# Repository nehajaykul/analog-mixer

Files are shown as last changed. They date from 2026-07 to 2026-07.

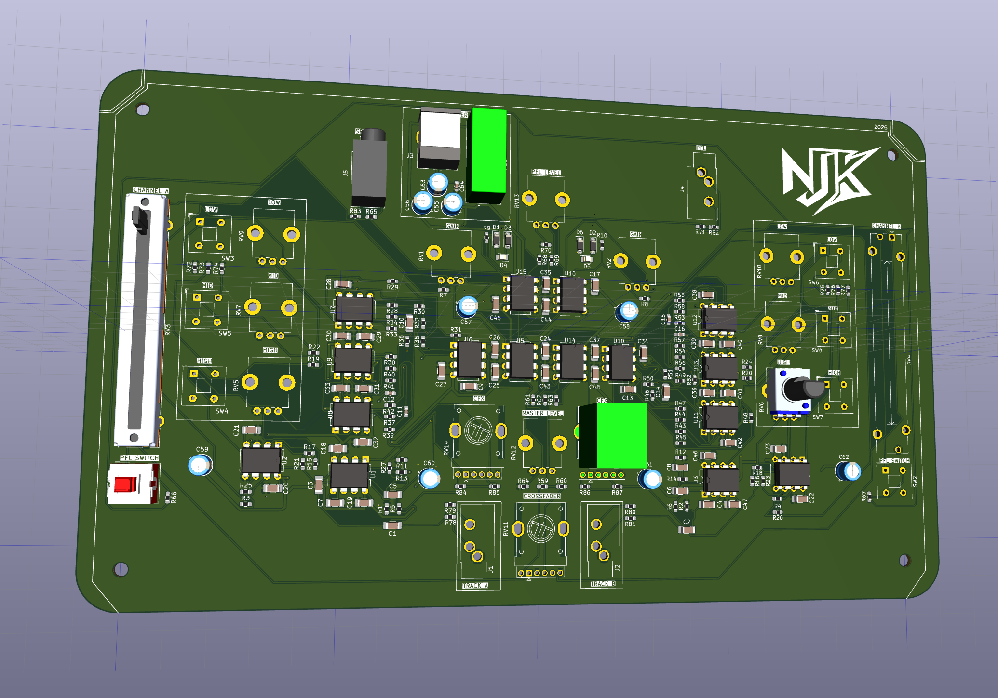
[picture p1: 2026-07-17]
docs/board_top.png

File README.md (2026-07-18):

# 2-Channel-Analog-DJ-Mixer

A fully analog 2-channel DJ mixer designed from first principles, 
simulated in LTspice, and laid out in KiCad for JLCPCB fabrication.

## Signal Chain

[3.5mm Input] → [L+R Sum] → [Sallen-Key HPF] → [SVF EQ Stage 1: 200Hz]
    → [SVF EQ Stage 2: 4kHz] → [Gain/Trim] → [Channel Fader]
    → [Crossfader] → [Virtual-Earth Sum] → [Master Output]

## Features

- 3-band parametric EQ per channel (HI/MID/LOW) with kill switches
- Cascaded Kerwin-Huelsman-Newcomb state-variable filters; Qs chosen for maximum passband flatness
  - Stage 1: f₀ = 200 Hz, Q = ~1.0
  - Stage 2: f₀ = 4 kHz, Q = ~.83
- Reduced summing-node phase cancellation, achieving <1.1 dB response variation across the band-pass (200 Hz–4 kHz)
- Pre-fader listen (PFL) cue system with headphone output; tapped after gain/trim stage and before channel fader
- Clipping LED indicator with 9.1V zener threshold (~11V signal threshold)
- Isolated ±15V dual-rail power supply (Traco TMR 6-1223)
- 15+ NE5532/TL072 op-amps throughout signal path

## Specifications

| Parameter | Value |
|---|---|
| Input | 3.5mm TRS, line level |
| EQ crossovers | 200 Hz, 4 kHz |
| EQ range | Cut to +14 dB per band |
| Power supply | 12V DC input → ±15V isolated |
| Op-amps | NE5532 (signal path), TL072 (monitor path) |
| PCB | 2-layer, JLCPCB fabrication |

## Repository Structure

```
/ltspice     — LTspice simulation files (.asc) for each circuit stage
/kicad       — KiCad schematic (.kicad_sch) and PCB layout (.kicad_pcb)
/gerbers     — Fabrication files for JLCPCB 2-layer PCB production
/docs        — Schematic PDF, simulation result plots, BOM
README.md    — Project overview
```

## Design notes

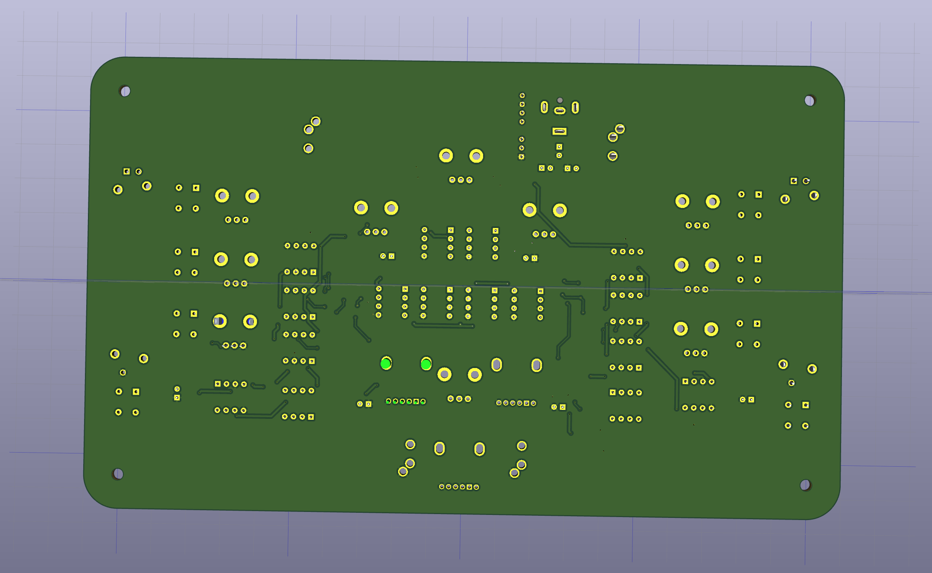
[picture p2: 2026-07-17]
docs/board_bottom.png

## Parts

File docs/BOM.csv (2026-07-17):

Id | Designator | Footprint | Quantity | Designation | Supplier and ref
1 | C19,C29,C28,C25,C14,C9,C45,C18,C42,C4,C41,C8,C32,C36,C47,C23,C1,C6,C44,C35,C46,C30,C26,C2,C43,C31,C22,C17,C33,C48,C20,C10,C40,C27,C37,C7,C34,C5,C38,C21,C3,C13,C39,C24 | C_1206_3216Metric_Pad1.33x1.80mm_HandSolder | 44 | 100n
2 | R29,R85,R59,R60,R24,R46,R21,R81,R58,R50,R69,R63,R87,R80,R54,R4,R20,R36,R19,R43,R44,R67,R30,R35,R22,R79,R84,R53,R27,R78,R66,R52,R42,R23,R37,R38,R86,R28,R61,R3,R25,R34,R51,R26,R45 | R_0603_1608Metric_Pad0.98x0.95mm_HandSolder | 45 | 10K
3 | SW4,SW6,SW7,SW5,SW3,SW2,SW1,SW8 | SW_Push_2P1T_Toggle_CK_PVA1xxH1xxxxxxV2 | 8 | SW_SPST
4 | RV11,RV15,RV14 | Potentiometer_Bourns_PTV112-4_Dual_Vertical | 3 | 10K
5 | R18,R62,R17,R15,R16 | R_0603_1608Metric_Pad0.98x0.95mm_HandSolder | 5 | 3.3K
6 | J5,J2,J1,J4 | Jack_3.5mm_CUI_SJ1-3533NG_Horizontal_CircularHoles | 4 | AudioJack3
7 | R65,R83 | R_0603_1608Metric_Pad0.98x0.95mm_HandSolder | 2 | 47
8 | RV7,RV12,RV9,RV2,RV13,RV10,RV8,RV1,RV6,RV5 | Potentiometer_Bourns_PTV09A-1_Single_Vertical | 10 | 50K
9 | U1,U8,U3,U6,U5,U11,U7,U4,U12,U10,U13,U2,U14,U9 | DIP-8_W7.62mm | 14 | NE5532
10 | R74,R75,R73,R77,R72,R76 | R_0603_1608Metric_Pad0.98x0.95mm_HandSolder | 6 | 100
11 | R11,R1,R12,R5,R2,R64,R14,R13,R6 | R_0603_1608Metric_Pad0.98x0.95mm_HandSolder | 9 | 100K
12 | R48,R32 | R_0603_1608Metric_Pad0.98x0.95mm_HandSolder | 2 | 5K
13 | R47,R49,R33,R31 | R_0603_1608Metric_Pad0.98x0.95mm_HandSolder | 4 | 8.2K
14 | D4,D5 | LED_0805_2012Metric_Pad1.15x1.40mm_HandSolder | 2 | D
15 | C55,C56,C58,C62,C60,C59,C63,C57,C61 | CP_Radial_D5.0mm_P2.50mm | 9 | 22u
16 | D6,D3,D2,D1 | D_SOD-123 | 4 | 9.1
17 | R9,R10 | R_0603_1608Metric_Pad0.98x0.95mm_HandSolder | 2 | 390
18 | R40,R56 | R_0603_1608Metric_Pad0.98x0.95mm_HandSolder | 2 | 6K
19 | C15,C11,C16,C12 | C_0603_1608Metric_Pad1.08x0.95mm_HandSolder | 4 | 10n
20 | R71,R82 | R_0603_1608Metric_Pad0.98x0.95mm_HandSolder | 2 | 150
21 | RV4,RV3 | Potentiometer_Bourns_PTA4543_Single_Slide | 2 | 10K
22 | R68 | R_0603_1608Metric_Pad0.98x0.95mm_HandSolder | 1 | 7.8K
23 | U16,U15 | DIP-8_W7.62mm | 2 | TL072
24 | R8,R70,R7 | R_0603_1608Metric_Pad0.98x0.95mm_HandSolder | 3 | 500
25 | R57,R55,R39,R41 | R_0603_1608Metric_Pad0.98x0.95mm_HandSolder | 4 | 3.9K
26 | C64 | C_0603_1608Metric_Pad1.08x0.95mm_HandSolder | 1 | 100n
27 | J3 | BarrelJack_CUI_PJ-063AH_Horizontal | 1 | Barrel_Jack
28 | PS1 | CONV_TMR_6-1223 | 1 | TMR_6-1223

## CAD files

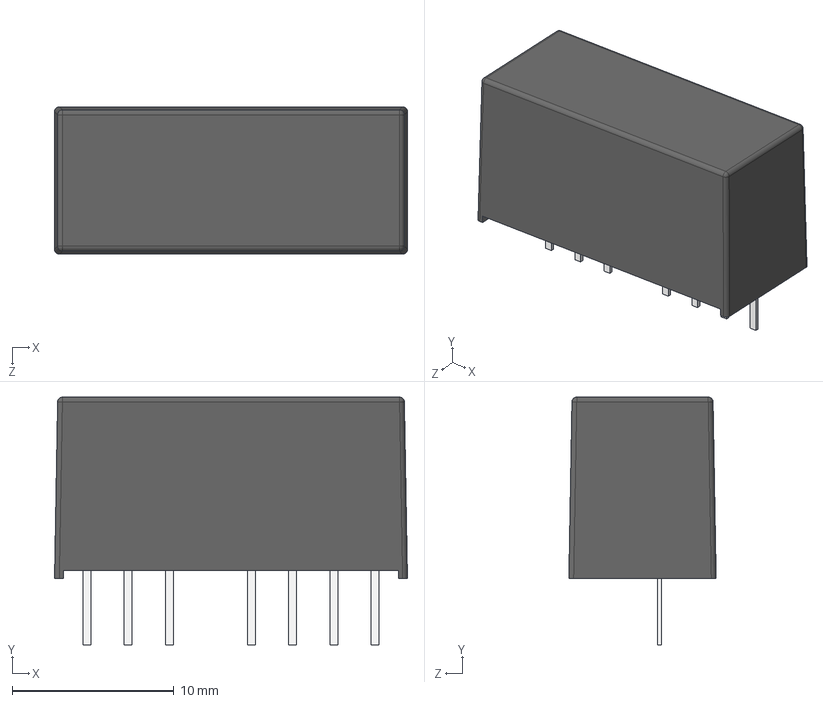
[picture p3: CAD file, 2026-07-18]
kicad/3dmodels/TMR_6-1223.step
21.8 x 15.3 x 9.10 mm

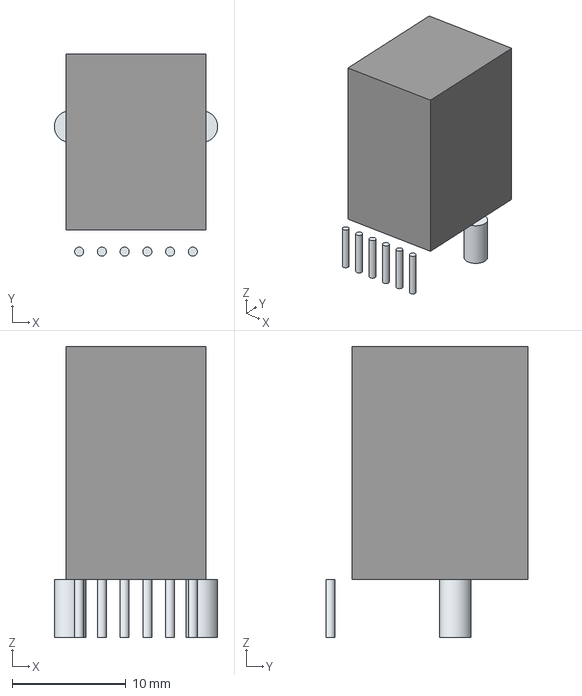
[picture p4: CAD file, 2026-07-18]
kicad/3dmodels/PTV112-4420A-B103.stp
14.4 x 17.8 x 25.6 mm
Leads x 8

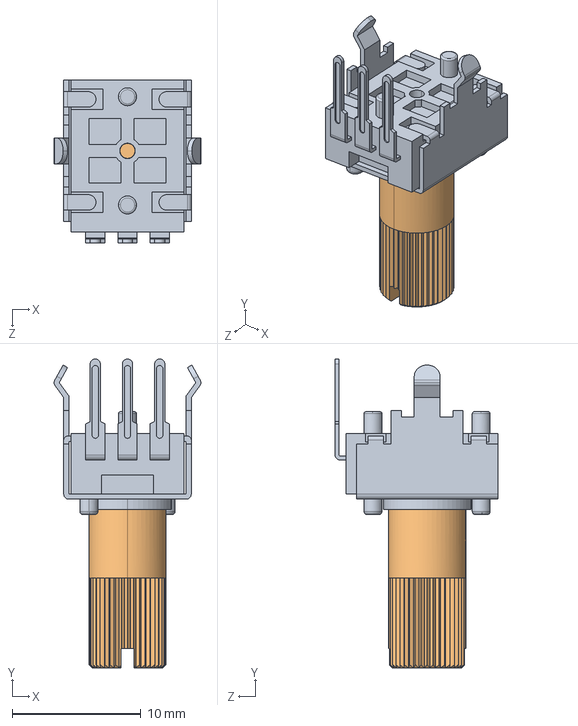
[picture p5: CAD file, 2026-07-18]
kicad/3dmodels/PTV09A-4020S-A503.stp
11.4 x 24.0 x 12.7 mm
PTV09A-4X20U-XXXX_1
PTV09A-4X20U-XXXX

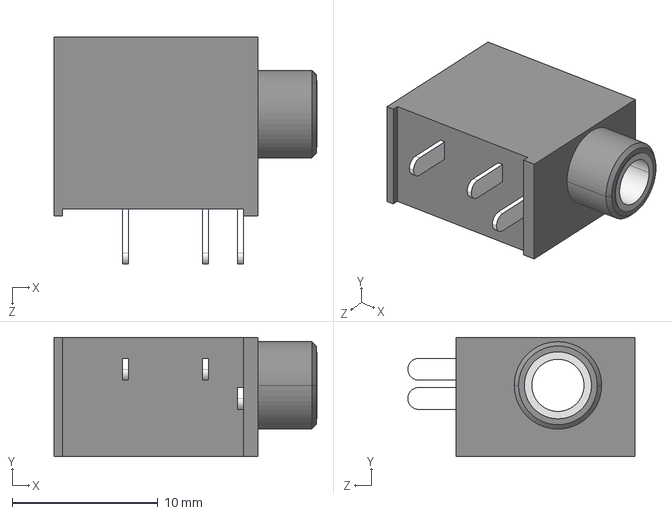
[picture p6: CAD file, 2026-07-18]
kicad/3dmodels/Same_Sky_SJ1-3533NG.step
18.1 x 8.20 x 15.6 mm

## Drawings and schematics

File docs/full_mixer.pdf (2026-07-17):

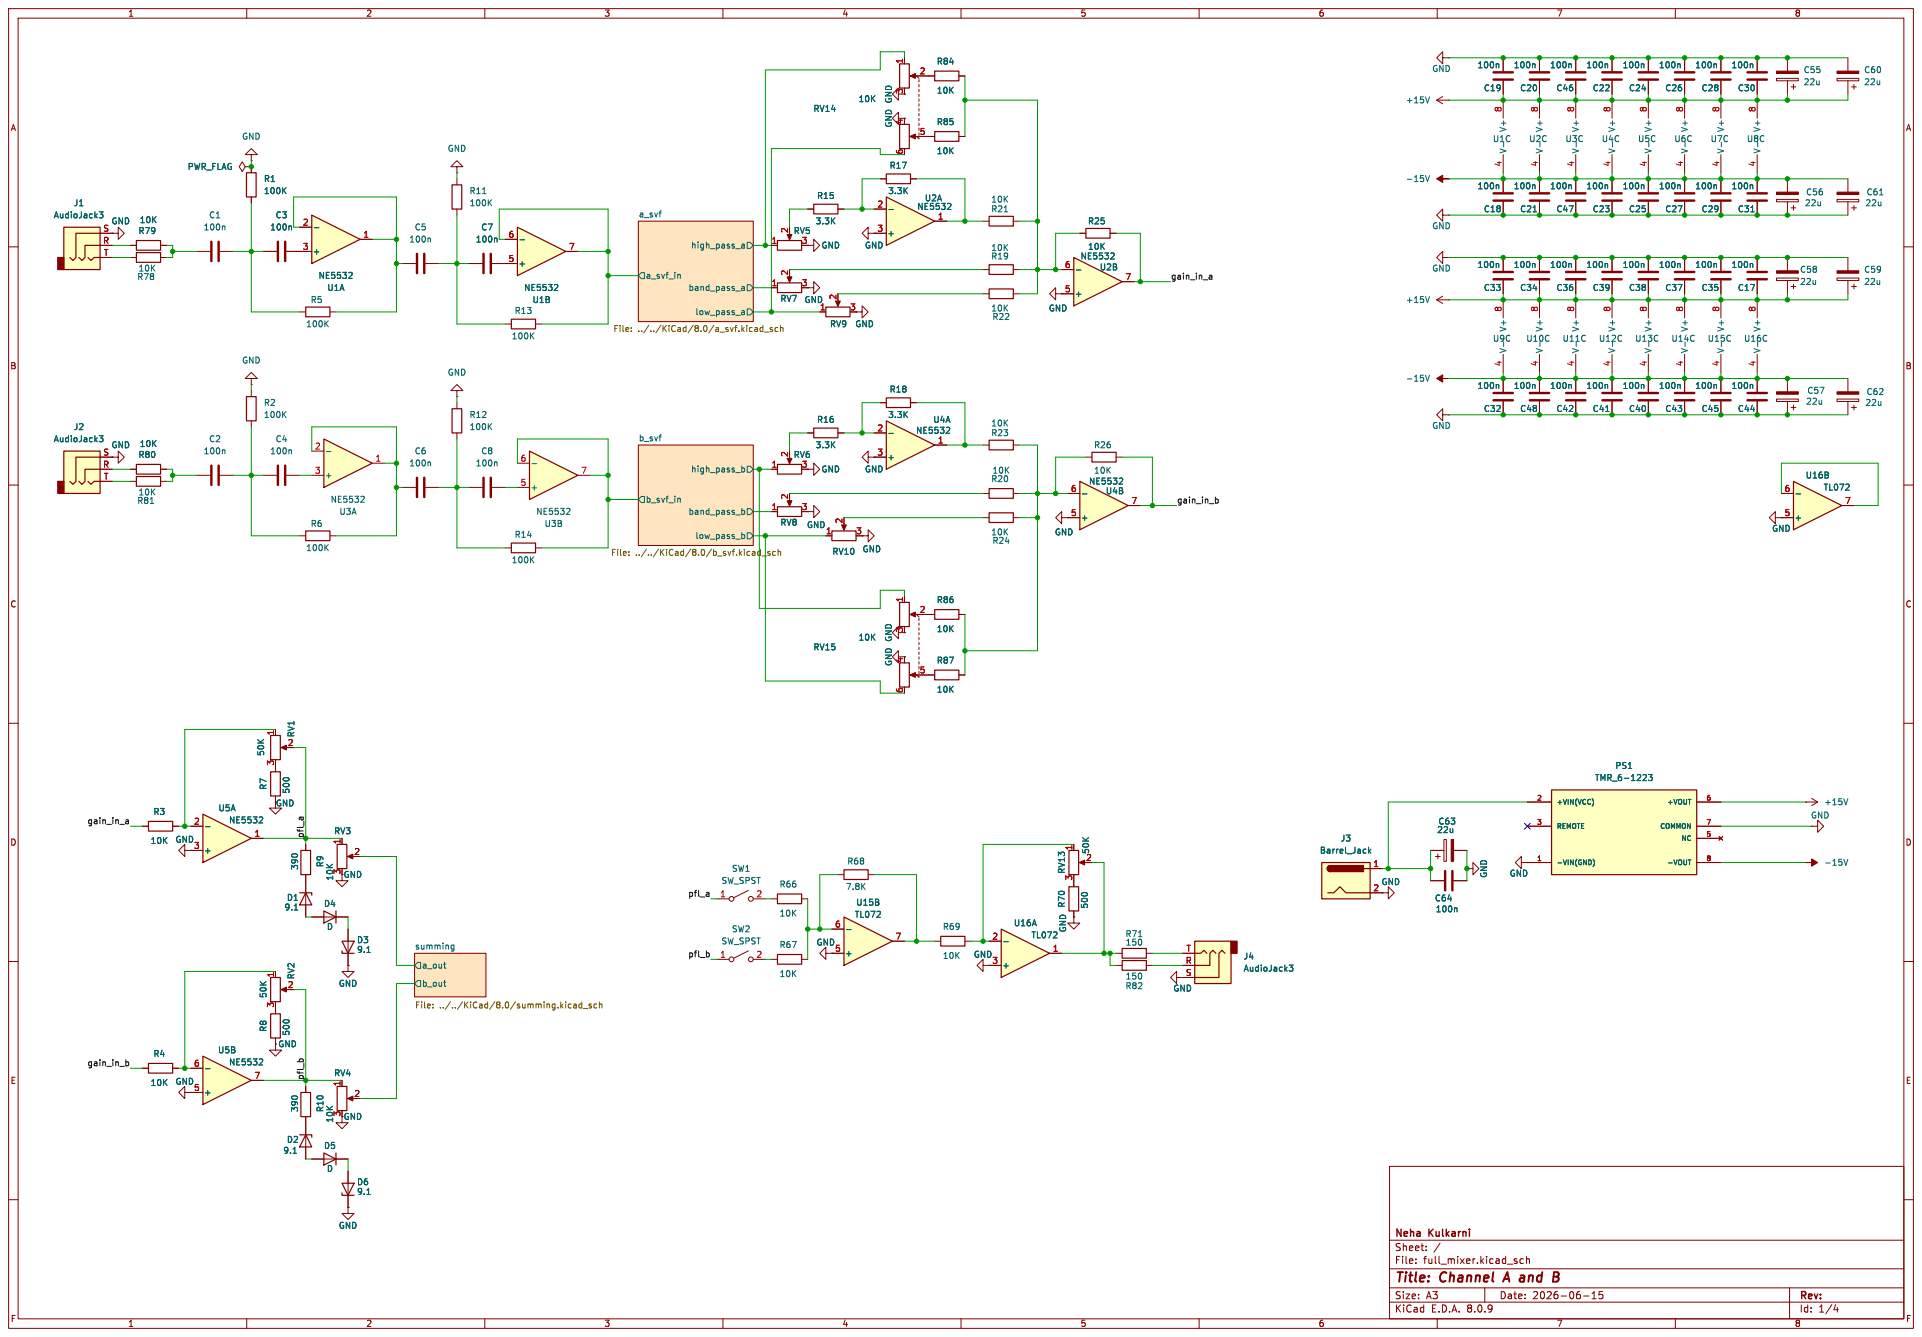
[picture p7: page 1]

6 GND GND GND GND GND

a_out b_out summing File: ../../KiCad/8.0/summing.kicad_sch

Id: 1/4 Title: Channel A and B

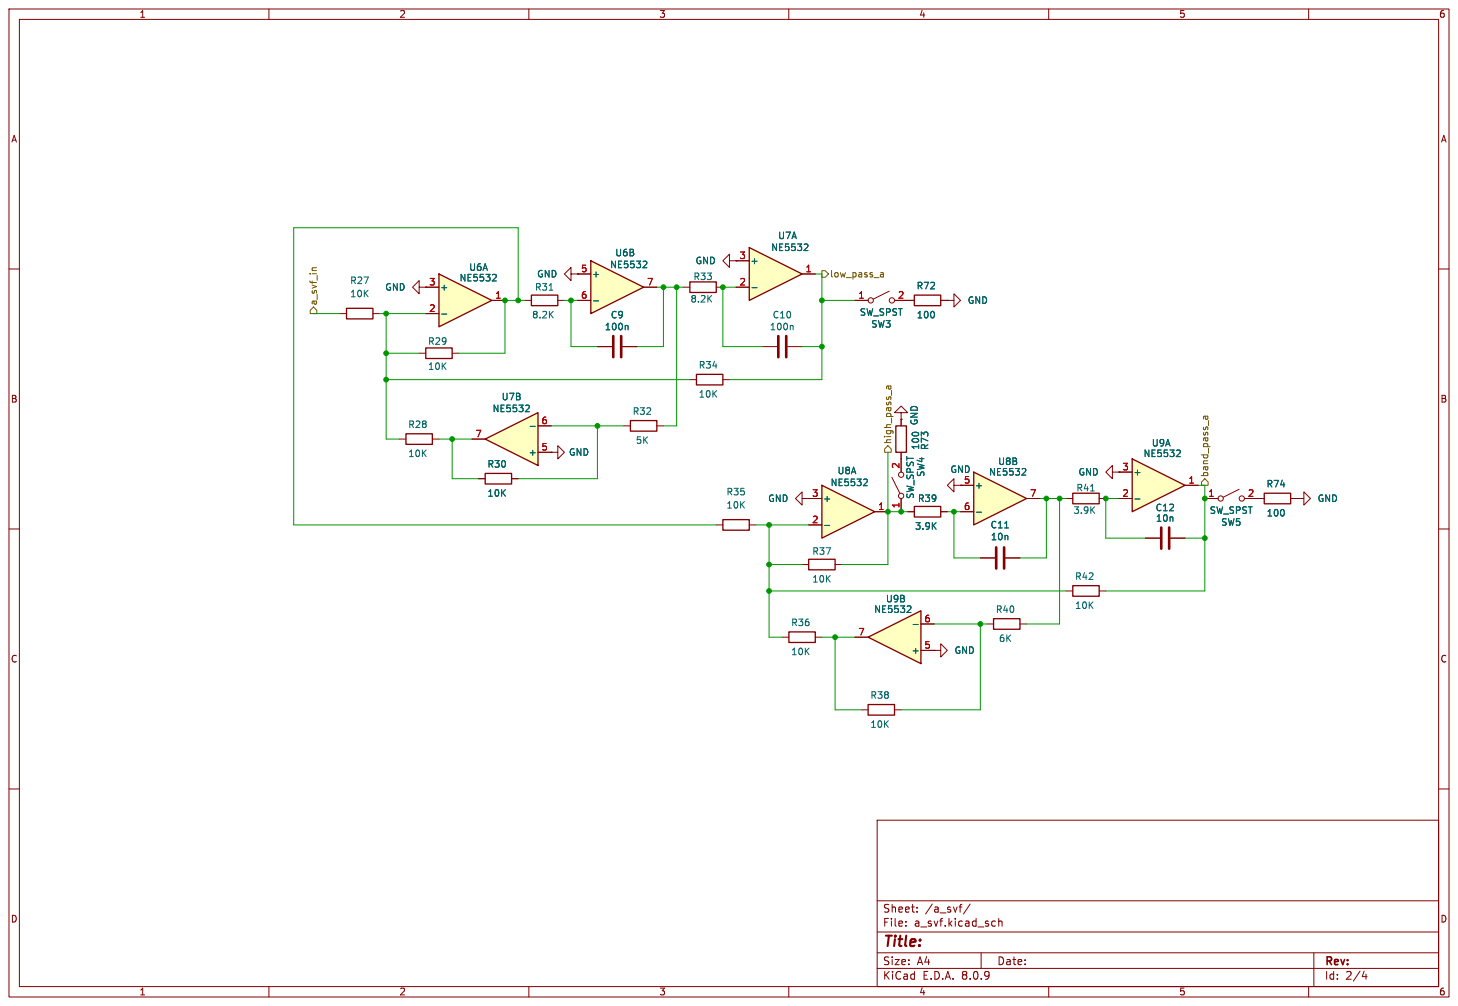
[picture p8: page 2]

Id: 2/4 Title: File: a_svf.kicad_sch Sheet: /a_svf/

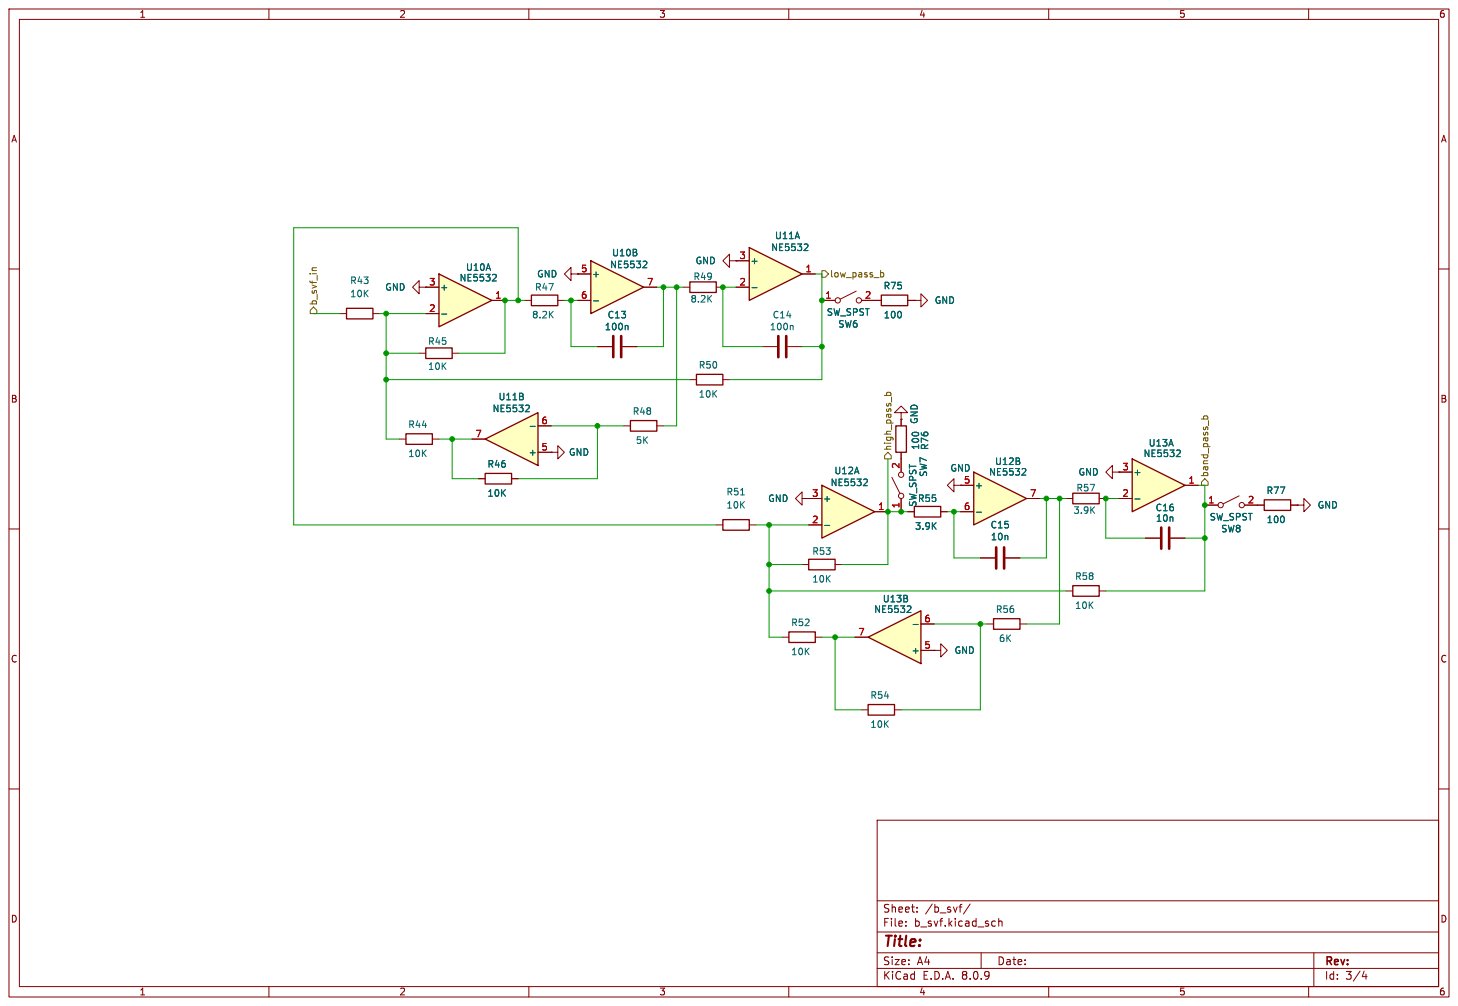
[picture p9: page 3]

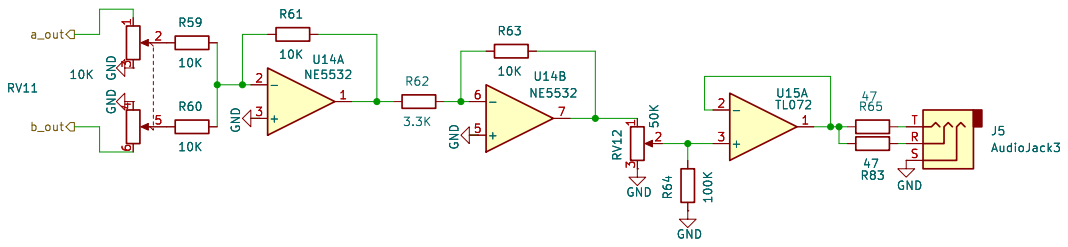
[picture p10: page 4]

Id: 4/4 Title: File: summing.kicad_sch Sheet: /summing/

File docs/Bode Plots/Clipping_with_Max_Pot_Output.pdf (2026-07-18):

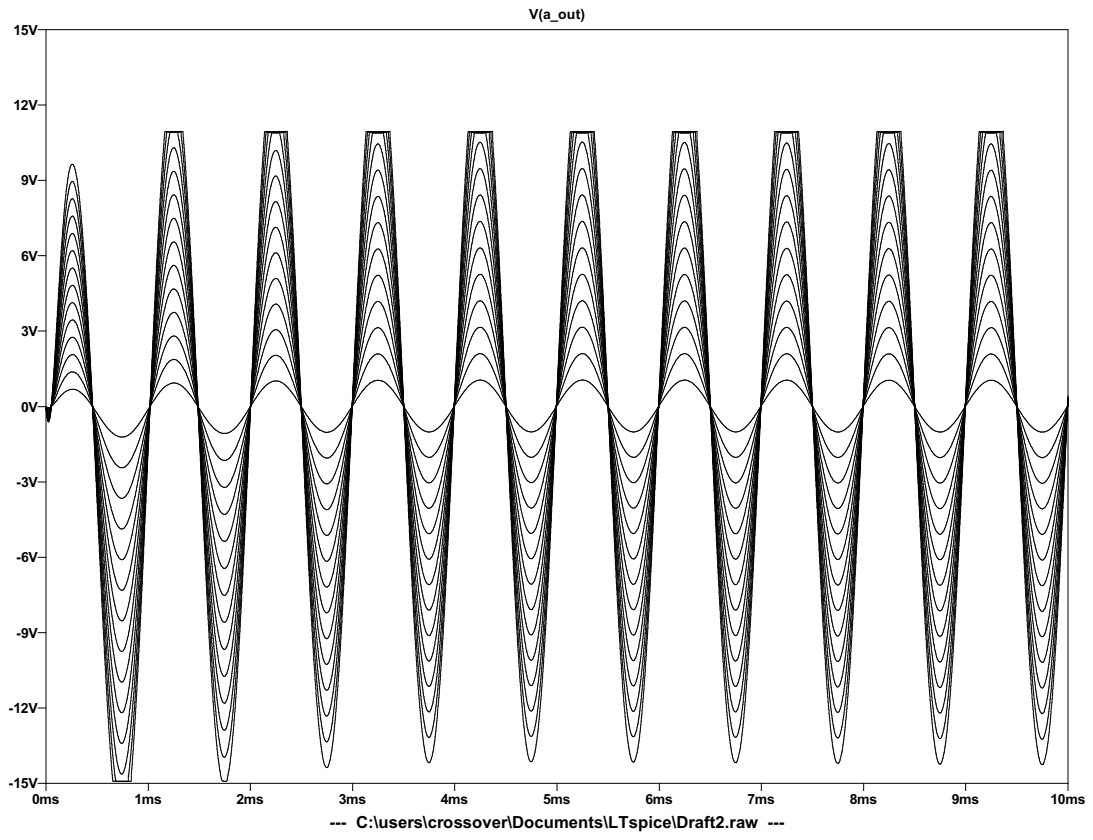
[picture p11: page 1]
V(a_out)

--- C:\users\crossover\Documents\LTspice\Draft2.raw ---

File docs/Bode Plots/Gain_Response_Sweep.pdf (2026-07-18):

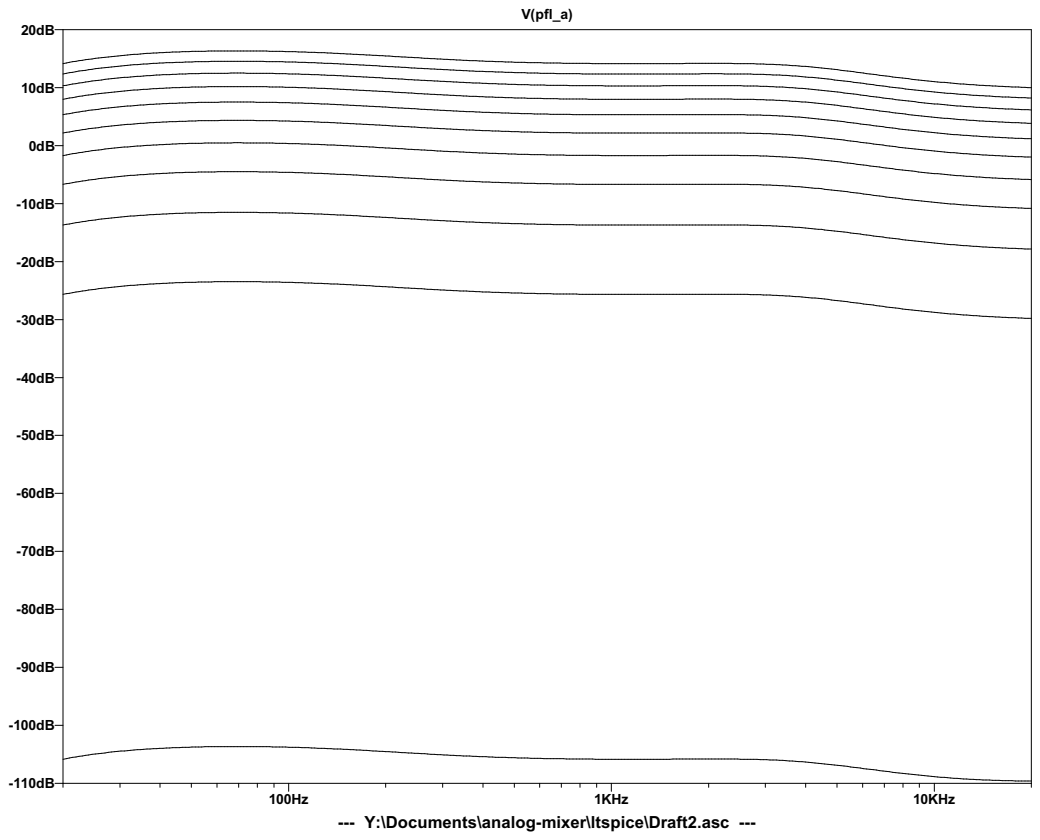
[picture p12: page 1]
1KHz; 10KHz; V(pfl_a)

--- Y:\Documents\analog-mixer\ltspice\Draft2.asc ---

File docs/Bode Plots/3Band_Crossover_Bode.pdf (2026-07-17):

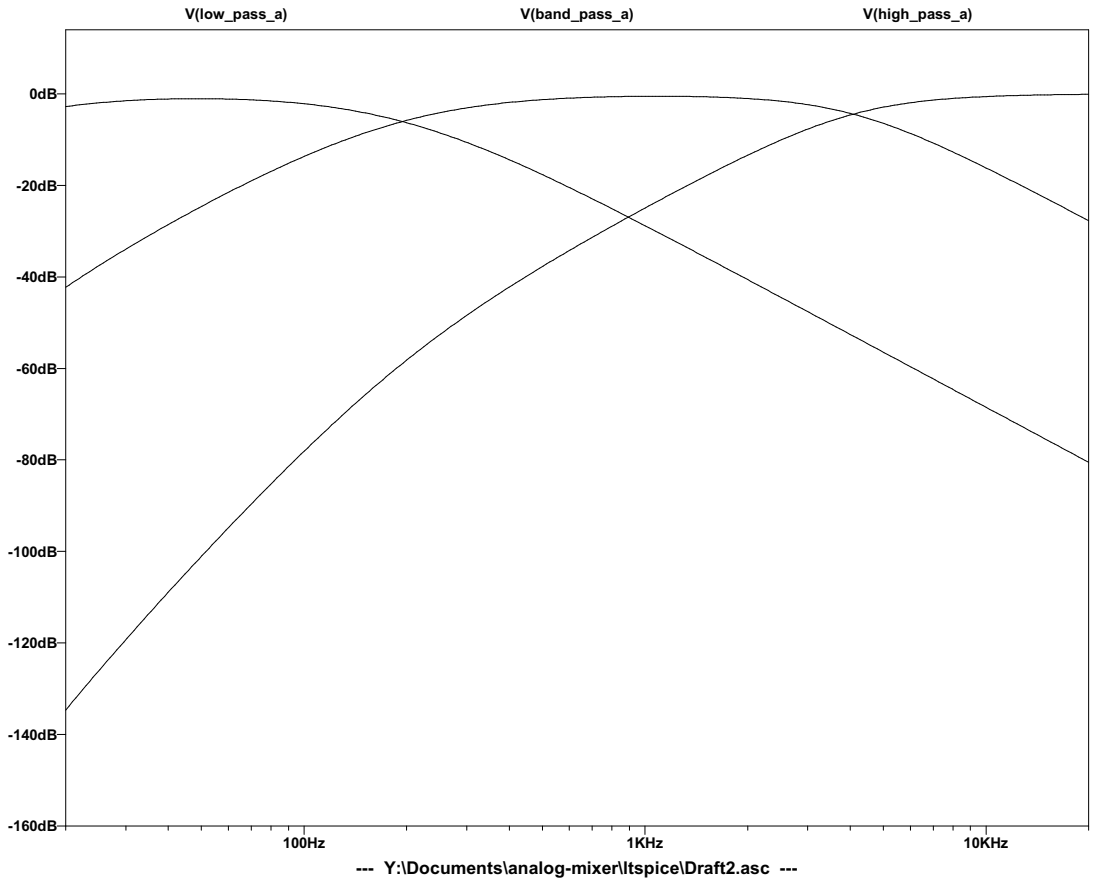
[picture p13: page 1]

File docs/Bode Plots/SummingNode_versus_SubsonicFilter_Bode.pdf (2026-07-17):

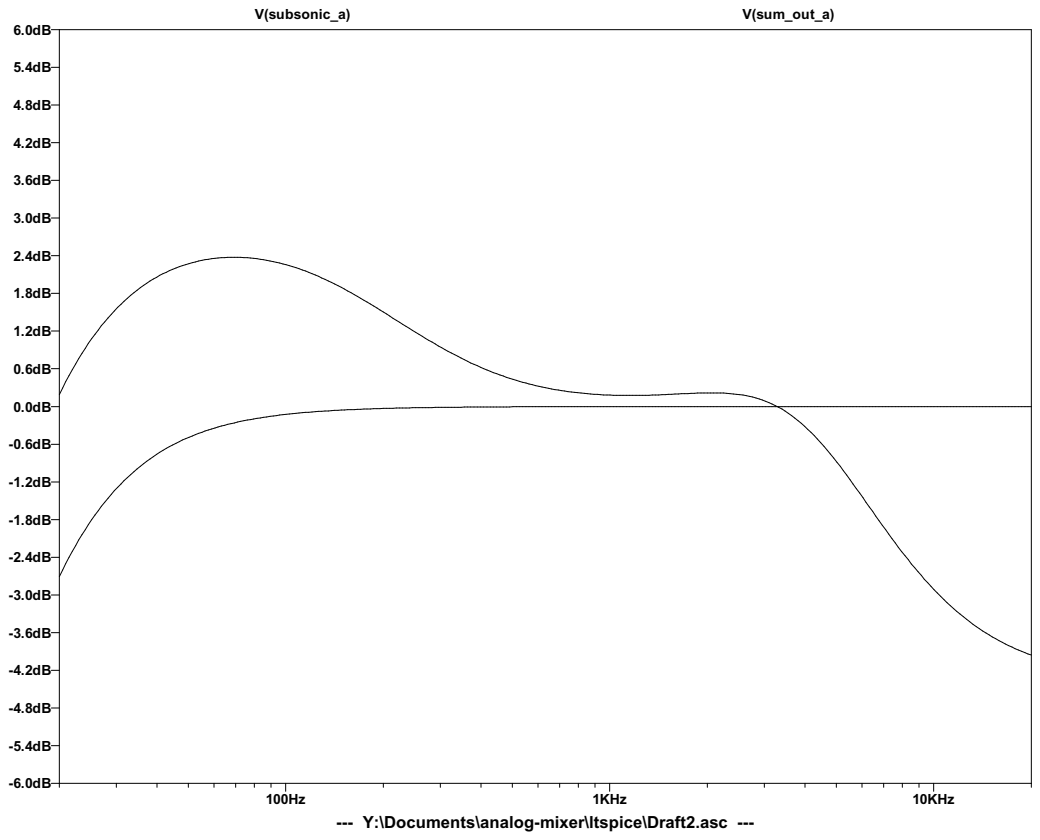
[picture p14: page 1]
1KHz; 10KHz; V(subsonic_a); V(sum_out_a)

--- Y:\Documents\analog-mixer\ltspice\Draft2.asc ---

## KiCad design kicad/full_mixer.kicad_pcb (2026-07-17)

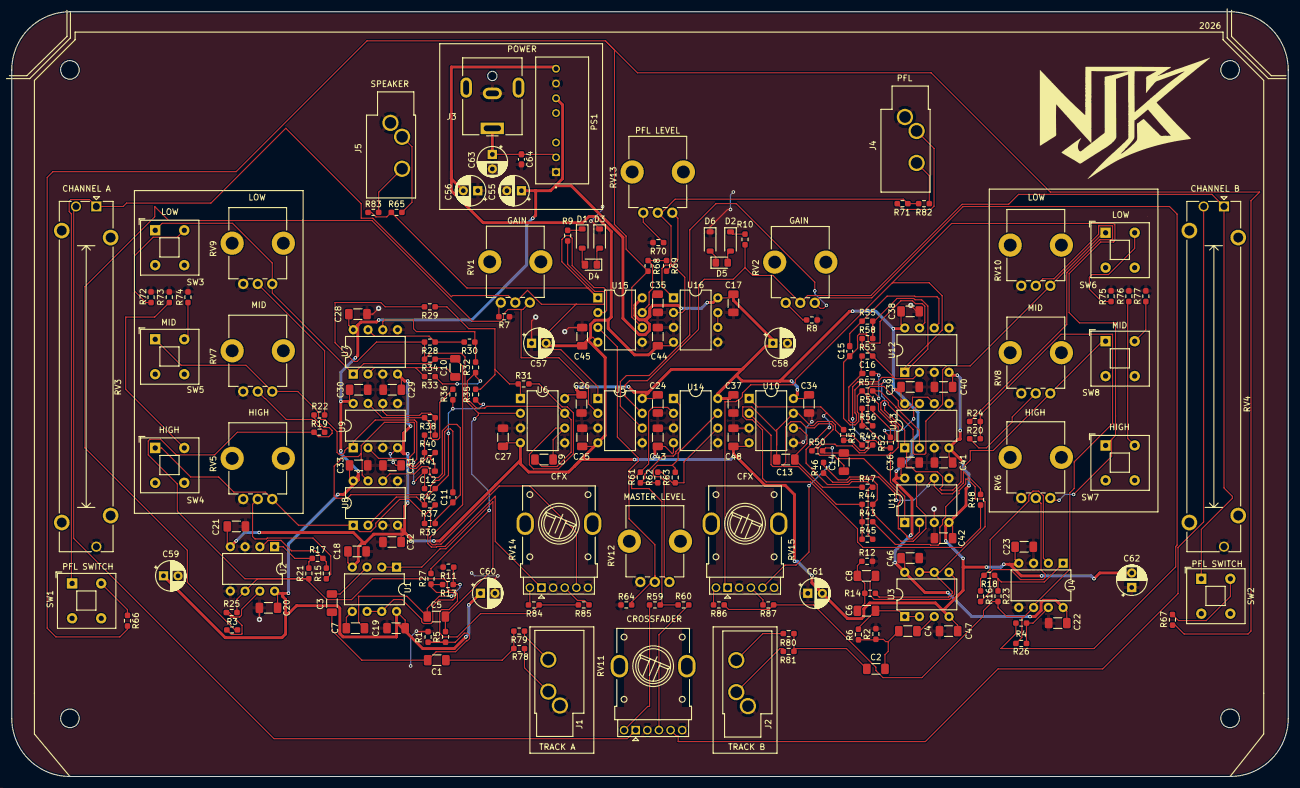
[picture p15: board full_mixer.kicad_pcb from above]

Board: 2 copper layers, 219.5 x 131.5 mm, 196 parts (0 on the bottom side), 112 nets.

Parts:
C1, C2, C3, C4, C5, C6, C7, C8, C9, C10, C13, C14, C17, C18, C19, C20, C21, C22, C23, C24, C25, C26, C27, C28, C29, C30, C31, C32, C33, C34, C35, C36, C37, C38, C39, C40, C41, C42, C43, C44, C45, C46, C47, C48: 100n; C_1206_3216Metric_Pad1.33x1.80mm_HandSolder
C11, C12, C15, C16: 10n; C_0603_1608Metric_Pad1.08x0.95mm_HandSolder
C55, C56, C57, C58, C59, C60, C61, C62, C63: 22u; CP_Radial_D5.0mm_P2.50mm
C64: 100n; C_0603_1608Metric_Pad1.08x0.95mm_HandSolder
D1, D2, D3, D6: 9.1; D_SOD-123
D4, D5: D; LED_0805_2012Metric_Pad1.15x1.40mm_HandSolder
J1, J2, J4, J5: AudioJack3; Jack_3.5mm_CUI_SJ1-3533NG_Horizontal_CircularHoles
J3: Barrel_Jack; BarrelJack_CUI_PJ-063AH_Horizontal
PS1: TMR_6-1223; CONV_TMR_6-1223
R1, R2, R5, R6, R11, R12, R13, R14, R64: 100K; R_0603_1608Metric_Pad0.98x0.95mm_HandSolder
R3, R4, R19, R20, R21, R22, R23, R24, R25, R26, R27, R28, R29, R30, R34, R35, R36, R37, R38, R42, R43, R44, R45, R46, R50, R51, R52, R53, R54, R58, R59, R60, R61, R63, R66, R67, R69, R78, R79, R80, R81, R84, R85, R86, R87: 10K; R_0603_1608Metric_Pad0.98x0.95mm_HandSolder
R7, R8, R70: 500; R_0603_1608Metric_Pad0.98x0.95mm_HandSolder
R9, R10: 390; R_0603_1608Metric_Pad0.98x0.95mm_HandSolder
R15, R16, R17, R18, R62: 3.3K; R_0603_1608Metric_Pad0.98x0.95mm_HandSolder
R31, R33, R47, R49: 8.2K; R_0603_1608Metric_Pad0.98x0.95mm_HandSolder
R32, R48: 5K; R_0603_1608Metric_Pad0.98x0.95mm_HandSolder
R39, R41, R55, R57: 3.9K; R_0603_1608Metric_Pad0.98x0.95mm_HandSolder
R40, R56: 6K; R_0603_1608Metric_Pad0.98x0.95mm_HandSolder
R65, R83: 47; R_0603_1608Metric_Pad0.98x0.95mm_HandSolder
R68: 7.8K; R_0603_1608Metric_Pad0.98x0.95mm_HandSolder
R71, R82: 150; R_0603_1608Metric_Pad0.98x0.95mm_HandSolder
R72, R73, R74, R75, R76, R77: 100; R_0603_1608Metric_Pad0.98x0.95mm_HandSolder
RV1, RV2, RV5, RV6, RV7, RV8, RV9, RV10, RV12, RV13: 50K; Potentiometer_Bourns_PTV09A-1_Single_Vertical
RV3, RV4: 10K; Potentiometer_Bourns_PTA4543_Single_Slide
RV11, RV14, RV15: 10K; Potentiometer_Bourns_PTV112-4_Dual_Vertical
SW1, SW2, SW3, SW4, SW5, SW6, SW7, SW8: SW_SPST; SW_Push_2P1T_Toggle_CK_PVA1xxH1xxxxxxV2
U1, U2, U3, U4, U5, U6, U7, U8, U9, U10, U11, U12, U13, U14: NE5532; DIP-8_W7.62mm
U15, U16: TL072; DIP-8_W7.62mm

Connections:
+15V: C17.1, C19.1, C20.1, C22.1, C24.1, C26.1, C28.1, C30.1, C33.1, C34.1, C35.1, C36.1, C37.1, C38.1, C39.1, C46.1, C55.1, C58.1, C59.1, C60.1, PS1.6 (+VOUT), U1.8 (V+), U2.8 (V+), U3.8 (V+), U4.8 (V+), U5.8 (V+), U6.8 (V+), U7.8 (V+), U8.8 (V+), U9.8 (V+), U10.8 (V+), U11.8 (V+), U12.8 (V+), U13.8 (V+), U14.8 (V+), U15.8 (V+), U16.8 (V+)
-15V: C18.2, C21.2, C23.2, C25.2, C27.2, C29.2, C31.2, C32.2, C40.2, C41.2, C42.2, C43.2, C44.2, C45.2, C47.2, C48.2, C56.2, C57.2, C61.2, C62.2, PS1.8 (-VOUT), U1.4 (V-), U2.4 (V-), U3.4 (V-), U4.4 (V-), U5.4 (V-), U6.4 (V-), U7.4 (V-), U8.4 (V-), U9.4 (V-), U10.4 (V-), U11.4 (V-), U12.4 (V-), U13.4 (V-), U14.4 (V-), U15.4 (V-), U16.4 (V-)
/a_svf/a_svf_in: R13.2, R27.1, U1.6 (-), U1.7
/a_svf/band_pass_a: C12.2, R42.2, RV7.1, SW5.1 (A), U9.1
/a_svf/high_pass_a: R37.2, R39.1, RV5.1, RV14.1, SW4.1 (A), U8.1
/a_svf/low_pass_a: C10.2, R34.2, RV9.1, RV14.6, SW3.1 (A), U7.1
/b_svf/b_svf_in: R14.2, R43.1, U3.6 (-), U3.7
/b_svf/band_pass_b: C16.2, R58.2, RV8.1, SW8.1 (A), U13.1
/b_svf/high_pass_b: R53.2, R55.1, RV6.1, RV15.1, SW7.1 (A), U12.1
/b_svf/low_pass_b: C14.2, R50.2, RV10.1, RV15.6, SW6.1 (A), U11.1
/gain_in_a: R3.1, R25.2, U2.7
/gain_in_b: R4.1, R26.2, U4.7
/pfl_a: R9.1, RV1.2, RV3.1, SW1.1 (A), U5.1
/pfl_b: R10.1, RV2.2, RV4.1, SW2.1 (A), U5.7
/summing/a_out: RV3.2, RV11.1
/summing/b_out: RV4.2, RV11.6
GND: C17.2, C18.1, C19.2, C20.2, C21.1, C22.2, C23.1, C24.2, C25.1, C26.2, C27.1, C28.2, C29.1, C30.2, C31.1, C32.1, C33.2, C34.2, C35.2, C36.2, C37.2, C38.2, C39.2, C40.1, C41.1, C42.1, C43.1, C44.1, C45.1, C46.2, C47.1, C48.1, C55.2, C56.1, C57.1, C58.2, C59.2, C60.2, C61.1, C62.1, C63.2, C64.2, D3.1 (K), D6.1 (K), J1.S, J2.S, J3.2, J4.S, J5.S, PS1.1 (-VIN(GND)), PS1.7 (COMMON), R1.2, R2.2, R7.1, R8.1, R11.2, R12.2, R64.1, R70.1, R72.2, R73.2, R74.2, R75.2, R76.2, R77.2, RV3.3, RV4.3, RV5.3, RV6.3, RV7.3, RV8.3, RV9.3, RV10.3, RV11.3, RV11.4, RV12.3, RV14.3, RV14.4, RV15.3, RV15.4, U2.3 (+), U2.5 (+), U4.3 (+), U4.5 (+), U5.3 (+), U5.5 (+), U6.3 (+), U6.5 (+), U7.3 (+), U7.5 (+), U8.3 (+), U8.5 (+), U9.3 (+), U9.5 (+), U10.3 (+), U10.5 (+), U11.3 (+), U11.5 (+), U12.3 (+), U12.5 (+), U13.3 (+), U13.5 (+), U14.3 (+), U14.5 (+), U15.5 (+), U16.3 (+), U16.5 (+)
unnamed: C1.1, R78.2, R79.2
unnamed: C1.2, C3.1, R1.1, R5.1
unnamed: C2.1, R80.2, R81.2
unnamed: C2.2, C4.1, R2.1, R6.1
unnamed: C5.2, C7.1, R11.1, R13.1
unnamed: C6.2, C8.1, R12.1, R14.1
unnamed: C9.2, R32.2, R33.1, U6.7
unnamed: C11.2, R40.2, R41.1, U8.7
unnamed: C13.2, R48.2, R49.1, U10.7
unnamed: C15.2, R56.2, R57.1, U12.7
unnamed: D1.2 (A), D4.2 (A)
unnamed: D1.1 (K), R9.2
unnamed: D2.2 (A), D5.2 (A)
unnamed: D2.1 (K), R10.2
unnamed: D3.2 (A), D4.1 (K)
unnamed: D5.1 (K), D6.2 (A)
unnamed: J1.R, R79.1
unnamed: J1.T, R78.1
unnamed: J2.R, R80.1
unnamed: J2.T, R81.1
unnamed: J4.R, R82.2
unnamed: J4.T, R71.2
unnamed: J5.R, R83.2
unnamed: J5.T, R65.2
unnamed: C63.1, C64.1, J3.1, PS1.2 (+VIN(VCC))
unnamed: R7.2, RV1.3
unnamed: R8.2, RV2.3
unnamed: R15.1, RV5.2
unnamed: R16.1, RV6.2
unnamed: R17.2, R21.1, U2.1
unnamed: R18.2, R23.1, U4.1
unnamed: R19.1, RV7.2
unnamed: R20.1, RV8.2
unnamed: R22.1, RV9.2
unnamed: R24.1, RV10.2
unnamed: R28.2, R30.1, U7.7
unnamed: R29.2, R31.1, R35.1, U6.1
unnamed: R36.2, R38.1, U9.7
unnamed: R44.2, R46.1, U11.7
unnamed: R45.2, R47.1, R51.1, U10.1
unnamed: R52.2, R54.1, U13.7
unnamed: R59.1, RV11.2
unnamed: R60.1, RV11.5
unnamed: R61.2, R62.1, U14.1
unnamed: R63.2, RV12.1, U14.7
unnamed: R68.2, R69.1, U15.7
unnamed: R70.2, RV13.3
unnamed: R71.1, R82.1, RV13.2, U16.1
unnamed: R84.1, RV14.2
unnamed: R85.1, RV14.5
unnamed: R86.1, RV15.2
unnamed: R87.1, RV15.5
unnamed: R66.1, SW1.2 (B)
unnamed: R67.1, SW2.2 (B)
unnamed: R72.1, SW3.2 (B)
unnamed: R73.1, SW4.2 (B)
unnamed: R74.1, SW5.2 (B)
unnamed: R75.1, SW6.2 (B)
unnamed: R76.1, SW7.2 (B)
unnamed: R77.1, SW8.2 (B)
unnamed: C3.2, U1.3 (+)
unnamed: C5.1, R5.2, U1.1, U1.2 (-)
unnamed: C7.2, U1.5 (+)
unnamed: R15.2, R17.1, U2.2 (-)
unnamed: R19.2, R21.2, R22.2, R25.1, R84.2, R85.2, U2.6 (-)
unnamed: C4.2, U3.3 (+)
unnamed: C6.1, R6.2, U3.1, U3.2 (-)
unnamed: C8.2, U3.5 (+)
unnamed: R16.2, R18.1, U4.2 (-)
unnamed: R20.2, R23.2, R24.2, R26.1, R86.2, R87.2, U4.6 (-)
unnamed: R3.2, RV1.1, U5.2 (-)
unnamed: R4.2, RV2.1, U5.6 (-)
unnamed: R27.2, R28.1, R29.1, R34.1, U6.2 (-)
unnamed: C9.1, R31.2, U6.6 (-)
unnamed: C10.1, R33.2, U7.2 (-)
unnamed: R30.2, R32.1, U7.6 (-)
unnamed: R35.2, R36.1, R37.1, R42.1, U8.2 (-)
unnamed: C11.1, R39.2, U8.6 (-)
unnamed: C12.1, R41.2, U9.2 (-)
unnamed: R38.2, R40.1, U9.6 (-)
unnamed: R43.2, R44.1, R45.1, R50.1, U10.2 (-)
unnamed: C13.1, R47.2, U10.6 (-)
unnamed: C14.1, R49.2, U11.2 (-)
unnamed: R46.2, R48.1, U11.6 (-)
unnamed: R51.2, R52.1, R53.1, R58.1, U12.2 (-)
unnamed: C15.1, R55.2, U12.6 (-)
unnamed: C16.1, R57.2, U13.2 (-)
unnamed: R54.2, R56.1, U13.6 (-)
unnamed: R59.2, R60.2, R61.1, U14.2 (-)
unnamed: R62.2, R63.1, U14.6 (-)
unnamed: R64.2, RV12.2, U15.3 (+)
unnamed: R65.1, R83.1, U15.1, U15.2 (-)
unnamed: R66.2, R67.2, R68.1, U15.6 (-)
unnamed: R69.2, RV13.1, U16.2 (-)
unnamed: U16.6 (-), U16.7

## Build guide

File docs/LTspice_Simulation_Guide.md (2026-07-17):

LTSPICE SIMULATION GUIDE
=========================

This document summarizes the LTspice simulation procedures used to
verify the analog mixer design, including frequency response, noise
performance, audio playback testing, potentiometer parameter sweeps,
and clipping behavior.

NOISE ANALYSIS
--------------
.noise V(sum_out_a) track_a dec 100 1 100000

Purpose: Analyze circuit noise performance across the audio band.

WAV OUTPUT TESTING
-------------------
.wave "suma_mix.wav" 16 44100 V(sum_out_a)
.wave "high_test.wav" 16 44100 V(high_pass_a)
.wave "band_test.wav" 16 44100 V(band_pass_a)
.wave "low_test2.wav" 16 44100 V(low_pass_a)
.wave "mix.wav" 16 44100 V(master_out)

Purpose: Export simulated signals as WAV files for audio evaluation.

.tran 0 10m 0 1u

Purpose: Analyze time-domain audio waveforms and verify signal behavior.

POT VALUES & STANDARD RUNS
----------------------------
.ac dec 100 20 20000
.step param master .001 .999 .1

Purpose: Evaluate circuit response across potentiometer ranges.

TRACK A

.param low_a=.999
.param band_a=.999
.param high_a=.999
.param ch_a=.45
.param fade_a=.001
.param cfx_a=.5

Note: .999 pot values are used for testing voltage clipping.

TRACK B

.param low_b=.5
.param band_b=.5
.param high_b=.5
.param ch_b=.45
.param fade_b=.001
.param cfx_b=.5

Note: .5 pot values are used for testing standard functionality.

MASTER

.param cross=.5
.param master=.5
.param pfl=.5

VOLTAGE CLIPPING
-----------------
.param amp=1
.tran 0 10m 0 1u
.step param amp 1 14 1

.model CLIPLED D(BV=9.1 IBV=0.001)

Note: CLIPLED is used to simulate a 9.1V Zener diode.

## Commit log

2026-07-17 LTspice full circuit, KiCad full schematic, & gerbers
    [channel_a_b-B_Mask.gbs, channel_a_b-B_Paste.gbp, channel_a_b-B_Silkscreen.gbo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]
2026-07-17 Docs updated: Schematic & PCB Rendering, BOM, Bode Plots
    [BOM.csv, full_mixer.kicad_pcb, full_mixer.kicad_sch]
2026-07-18 KiCad footprint & models updated, cached files removed
    [PTV09A-4020S-A503.stp, PTV112-4420A-B103.stp, Same_Sky_SJ1-3533NG.step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]
